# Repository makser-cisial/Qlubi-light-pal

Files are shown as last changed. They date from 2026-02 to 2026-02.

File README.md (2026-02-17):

# Qlubi-light-pal

A.M.D.G

A desktop buddy who’s there to connect when you feel most alone

Qlubi is a networked companion device that converts heart rate stress signals into anonymous light communication, enabling trusted groups to support each other remotely through subtle, non-verbal interaction.

<p float="left">
  
  
</p>

---

## What it is

Qlubi network-based device designed to connect groups working and living separately and provide accompaniment through its communicative light system. Composed of a microcontroller, button, LED strip, and limited 3D printed parts, the device allows user to create a network by which they can pick up on and engage with each other’s distress without surveillance or intrusion.

The project is open source and designed to be customised and built upon, turning each Qlubi into someone’s made to be buddy.

Watch the product video at: https://www.youtube.com/watch?v=_jfL0hginCQ
---

## Concept

Today’s world provides a uniquely extreme environment in the way that it has pushed social connection to its limit. No longer can one pick up on the body language of a colleague in the office to see they may be stressed and need a hand or a knowing glance. No one is there to notice when someone is stressed, so much so the person themselves doesn’t realise it either without the outside prodding of others. 

Qlubi exists to fill that space, bringing these non-verbal forms of communication and connection to the digital world. By syncing one’s heart rate data with the device, users can create trusted networks with friends where when one’s heart rate rises from stress, and an anonymous signal is sent throughout the network, allowing others to interact with their devices to send back heartening signals through warm waves of pulsating light.

---

## Key Questions

### Who’s connected?

Users can form intentional networks of devices with whoever they please, connecting through personal servers via MQTT protocol meaning you're only connected to those you know and trust.

### What travels through the network?

Only anonymised messages that shift the states of the devices as all heart rate data is processed locally keeping one’s data private and secure. You don’t know who’s stress you’re responding to or what may be stressing them out allowing outreach without exposure and support without interference.

### How come light?

Light allows for a soothing and non-jarring means of communication when compared to sound, allowing it to only just catch the users attention and alert them out of their stress cycle without activating any further stress response. Being light based also allows the device to function in public spaces without disturbing those near which also contributes to a more intimate and deliberate experience as you know someone out there is paying attention to your call.

### How does one interact with the device?

When receiving signals, users can pat their Qlubi’s head, pressing the internal button and thus responding and interacting with the network, turning what would have been cold keyboard clicks into an extension of warm physical touch. 

---

## How it works

- User’s heartrate data is streamed from their smart watch or device to their paired Qlubi system via a local HTTP connection  
- After establishing a baseline, a maintained spike in heartrate indicating stress may be detected  
- When this occurs, the system sends a signal via MQTT to all other active devices in the system who begin to gently pulsate indicating that there is a in-network user in distress  
- Those receiving this message can then tap their Qlubi on the head three times, sending a signal back to the original device telling it to begin pulsating a different colour indicating that they are stressed and someone has reached out  
- When there are no other active users or there is no response after a certain time the Qlubi acts autonomously, entering a slightly different alert mode simply to alert the user of their stress  

Through this others can pick up on what their friends and colleagues are feeling, allowing them to step into their space and be there through the Qlubi

---

## Design Intent

- Qlubi is currently developed as a prototype device intended for experimentation, iteration, and open maker development.
- The system is intended for both end users and makers interested in building connected devices, wearable interaction systems, and emotional communication tools.
- The device is built around:
  - Lolin S2 Mini microcontroller  
  - WLED compatible LED strip  
  - Lolin 1 Button  
  - A wearable capable of monitoring heart rate  
  - A sensor logger app on a mobile device synced with the wearable
- Everything included is open licence and intended to be shared, modified, and expanded upon by the community.

---

## Hardware

- The hardware platform is centred around the Lolin S2 Mini which provides wireless connectivity, local processing, and LED control capabilities.
- The lighting system uses compact WLEDs with 7 LEDs which provide device state feedback and interaction visualisation.
- The button is the Lolin 1 Button which provides touch interaction and allows users to physically respond to incoming network signals.
- Users must 3D print their own parts using the included enclosure and component mounting models provided in the repository.

---

## Software and System Behaviour

- The board firmware and laptop side software together manage the communication and interaction logic of the system.
- Firmware functionality includes:
  - Subscribing to wearable heart rate data streams
  - Establishing and maintaining a baseline heart rate
  - Detecting deviations from baseline values
  - Managing device operational states
- Network behaviour includes:
  - Communication using MQTT messaging
  - Broadcasting distress signals between devices
  - Handling pairing messages and confirmations
  - Managing response signals between users
- Laptop software functionality includes:
  - Acting as a bridge between wearable sensor logger data and MQTT broker topics
  - Publishing heart rate data to Qlubi devices
- Interaction logic includes:
  - Button tap sequences used for mode switching
  - Pairing initiation and confirmation
  - Triggering response signals
- LED behaviour communicates:
  - Device state
  - Incoming network signals
  - Pairing status
  - Response confirmation through pulsing patterns and colour changes

---

## Open Source from code to form

Hardware: open, reproducible and customisable through simple 3D printing  
Software: open source Circuit Python  
Concept: adaptable and extendable  (GitHub) 

Whilst having a specific aim, Qlubi’s framework allows for an extremely wide array of customisation as users print parts to make their Qlubi theirs and open code allows one to stack on as many features as they can think of.

---

## Build Requirements

- All that is needed is a 3D printer.
- No soldering or glueing required as all parts are friction fits and the enclosure is designed to hold every internal component securely.
- The only adhesive required is a strip of double sided tape used to hold the LED strip to the back wall of the enclosure.

---

## Assembly

There will be a separate document that contains full assembly instructions, build order, and placement diagrams. This repository references that document for the physical build process.

---

## Setup and Configuration

This section will contain:

- Firmware installation instructions  
- Network configuration guidance  
- MQTT broker setup instructions  
- Wearable sensor logger configuration  
- Device pairing instructions  
- Troubleshooting information  

This will be completed once the full GitHub repository structure is finalised.

---

## Customisation

- Qlubi can be printed in any colours and materials the user wants.
- Decorative and functional variations can be created using the provided 3D files.
- Expansion geometry allows attachments and custom add-ons to connect cleanly with the base device.
- All enclosure files and firmware are available for users to edit, modify, and extend to suit personal or project specific needs.

---

## Network Requirements

- One needs access to a server to set up a Qlubi network.
- The server acts as the MQTT broker which manages communication between wearable devices and all connected Qlubi units.

---

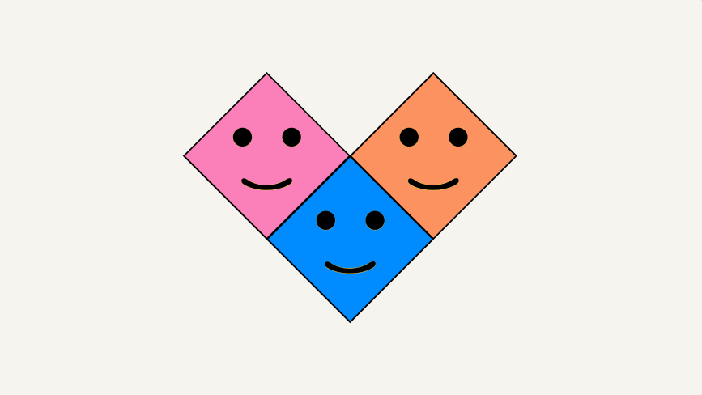
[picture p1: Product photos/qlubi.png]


## Why this matters

Qlubi incorporates this connected but anonymous form of network to both remove the shame of reaching out that drives disconnection whilst capitalizing on this alternate medium to take connection beyond where it could in the physical world. One can reach out through simply because there is someone that needs to be reached and can do so without feeling uncertain as to whether it is their place to. In a world that removes intimate connection, Qlubi highlights it and advances it

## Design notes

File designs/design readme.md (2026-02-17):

# Qlubi Face & Body Assembly Guide

Qlubi is composed of two primary printed structures: the **Face module** and the **Body enclosure**.

Each module has its own folder and printing instructions.  
You must complete the instructions within those folders before proceeding to final assembly described here.

This guide explains how both modules integrate into the complete Qlubi device.

---

## Overview of Composition

Qlubi consists of:

- Face Print  
- Body Enclosure (Base + Upper Shell)  
- Lolin S2 Mini  
- LEDs  
- Optional Hats  
- Boots  

No adhesive is required for standard assembly. All components are designed as friction-fit or mechanical lock-fit.

---

# Step 1 — Complete Folder Instructions

Before continuing:

1. Follow all printing instructions inside the **Face folder**.
2. Follow all printing instructions inside the **Body folder**.
3. Ensure all supports are removed cleanly.
4. Confirm scaling has not been altered in your slicer.

Only proceed once both printed assemblies are ready.

---

# Step 2 — Installing the Face into the Body

The Face is designed to slide vertically into the front cavity of the Body enclosure.

## Installation Process

1. Hold the Body upright.
2. Align the Face print with the internal guide rails.
3. Slide the Face downward slowly.
4. Continue sliding until it reaches the bottom.

At the base of the Body there is a **raised locking feature**.  
The Face contains a matching recess.

Push firmly until the Face locks into place against the raised internal stop.

The Face should:

- Sit flush  
- Not wobble  
- Not lift upward without deliberate force  

If resistance occurs:

- Check for leftover support material  
- Check for minor print stringing along rail edges  

Do not force excessively.

---

# Step 3 — Assembling the Lolin S2 Mini

Assemble your **Lolin S2 Mini** by 
1. soldering on the pin connectors
2. cutting off the excess from the button to ensure the board lies as flush as possible
3. place on the button in the correct orientation and then the LED wires accordingly going red, black green from the bottom right up

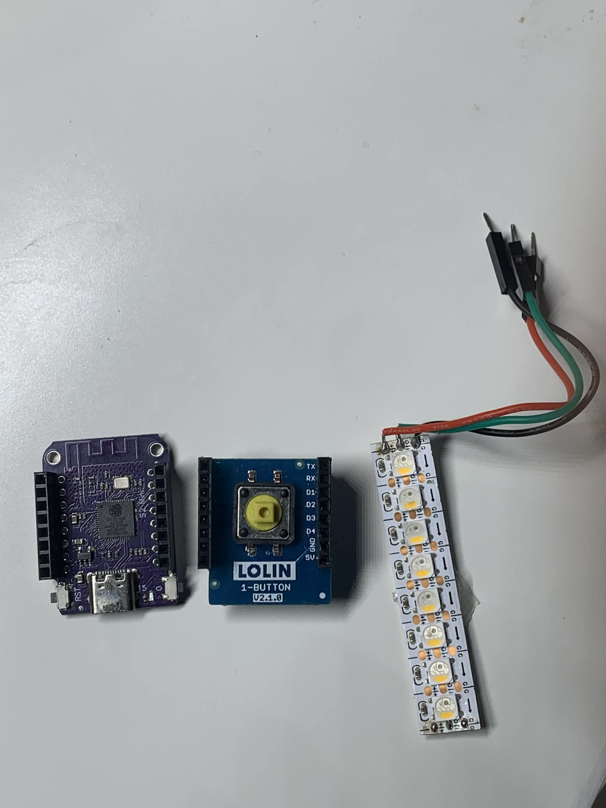
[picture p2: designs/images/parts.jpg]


Ensure:

- Pins are correctly soldered  
- LEDs are properly connected  
- No exposed contacts are shorting  

Test functionality before enclosure installation if possible.

---

# Step 4 — Installing the Board into the Base

1. Insert the Lolin S2 Mini into the base cavity.
2. Orient it so the **USB-C port faces the rear opening**.
3. Seat the board flat against the internal platform.

The USB-C port must remain accessible from the back of Qlubi for charging and programming.

Do not trap wires beneath the board.

---

# Step 5 — Installing the LEDs

1. Attach the LEDs to their designated mounting points.
2. Feed LED wiring through the bottom routing holes.
3. Route wires cleanly toward the base.

**Important:**

- Stick the LEDs to the **back interior wall** of the Body.  
- Ensure LEDs face forward toward the Face diffuser area.  
- Confirm no wires obstruct the LED light output.  
- Avoid crossing wires over the LED surface.  

Clean cable routing improves light diffusion and prevents shadowing.

---

# Step 6 — Closing the Body

Once:

- Face is locked in place  
- Board is seated  
- LEDs are positioned  
- Wiring is routed cleanly  

Place the **top shell** onto the Body.

Press down evenly until it seats fully.

---

# Step 7 — Accessories

## Hats

Insert any compatible hat into the top head slot.  
Hats are swappable and require no adhesive.

## Boots

Place boots into their corresponding lower body positions.  
They are designed as friction-fit components.

---

# Adhesives

No glue is required.

However, if your printer tolerances are loose, you may optionally use:

- Small pieces of double-sided tape  
- Minimal removable adhesive  

Avoid permanent glue unless modification is intentional.

---

# Final Check

Before powering on:

- Confirm USB-C port alignment  
- Confirm no wires are pinched  
- Confirm LEDs are unobstructed  
- Confirm Face is fully seated  

Qlubi should now be fully assembled and ready for operation.

---

# Troubleshooting

If components do not fit:

- Recheck scaling in slicer  
- Confirm correct STL files were used  
- Inspect for print warping  
- Remove residual supports fully  

---

Qlubi is modular by design.  
Face styles, hats, and colours can be interchanged without reprinting the full enclosure.

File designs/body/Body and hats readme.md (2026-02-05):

# Qlubi Body and Hats Printing Guide

The Qlubi body is fully 3D printed and designed to be easily produced using the files included in this repository. Users may either print the entire body in one print or print individual parts separately to customise colours, materials, or finishes.

---

## Available Files

The repository contains multiple options depending on how you would like to print your Qlubi body.

### Qlubi Full

- `Qlubi full.stl`  
  Contains all body and hat components combined into a single print file. 

---

### Qlubi Body Zip

- `Qlubi body.zip`  
  Contains all Qlubi body components as separate files.  
  This allows users to print body sections individually or in different colours and materials.

---

### Hats Zip

- `Hats.zip`  
  Contains all hat components as separate files.  
  Hats can be printed individually and swapped depending on user preference.

---

## Printing Options

Users have two primary approaches when printing Qlubi.

---

## Option 1 — Print Entire Body at Once

1. Import `Qlubi full.stl` into your slicer.
2. Split the model into objects and orient as relevant as can be seen in image.
3. Enable supports as required.

### Recommended Print Settings

- Infill: **5–15%**
  - Use higher infill for lighter or more translucent materials to reduce light leakage.
  - Use lower infill for darker or more opaque materials.

- Layer Height: **0.16 mm**

- Supports: **Snug supports recommended**

This method is the fastest and simplest way to produce a complete Qlubi enclosure.

---

## Option 2 — Print Parts Separately

Users may unzip the body and hat archives to print components individually.

### Benefits of Printing Parts Separately

- Allows multi-colour printing
- Allows mixing materials
- Enables easier reprinting of damaged or modified parts
- Supports aesthetic customisation and personal styling

### Process

1. Extract `Qlubi body.zip`.
2. Extract `Hats.zip`.
3. Import individual STL files into your slicer.
4. Arrange and print parts according to your chosen colour or material layout.

Recommended print settings remain the same as printing the full body unless specific materials require adjustment.

---

## Material Considerations

- Lighter or translucent filaments may allow more internal light leakage and benefit from higher infill percentages.
- Darker or opaque filaments naturally reduce light leakage.

---

## Assembly

Line up all printed parts and press them together as designed.

Ensure that the springs are correctly placed in position between the base and the upper casing before fully closing the body. Proper spring placement is required for correct button interaction and device function.

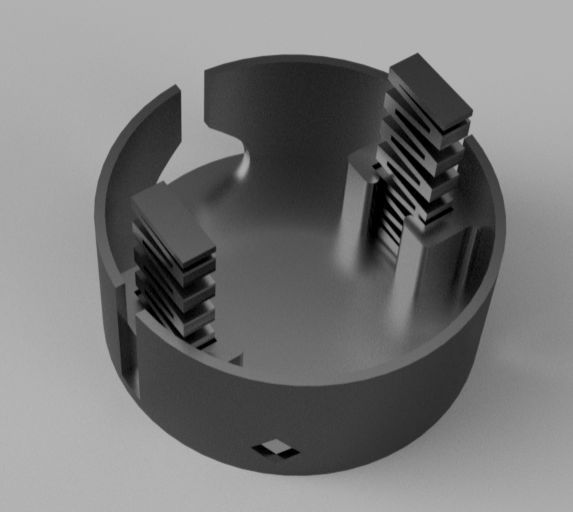
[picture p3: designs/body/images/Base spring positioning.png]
Spring positioning for base


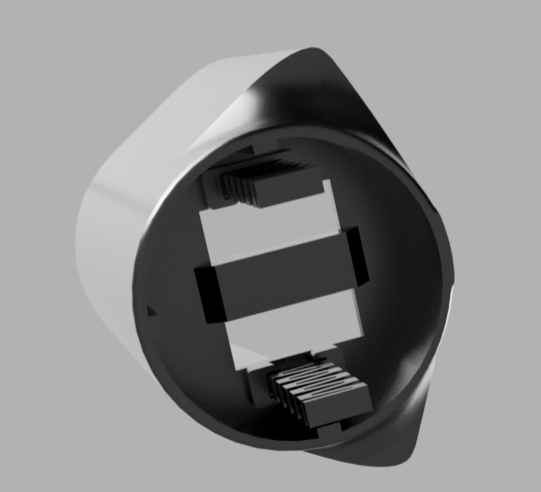
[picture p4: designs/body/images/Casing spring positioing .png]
Spring positioning for casing


---

## Troubleshooting

If parts do not fit correctly:

- Confirm scaling has not been altered in the slicer
- Confirm supports were removed cleanly
- Confirm correct parts were printed for the intended assembly

---

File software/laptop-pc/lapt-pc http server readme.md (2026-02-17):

# Laptop/PC HTTP Code Setup Guide

This folder contains the Laptop/PC HTTP code required to connect your Qlubi device to your HTTP server infrastructure to connect your app to your MQTT server broker and protecting your data..

To run this code, users must first configure a local Python environment on their computer.

This guide outlines the full setup process.

---

# Step 1 — Install a Python interpreter

You will need a Python IDE or runtime environment to execute the code in this folder.

You may use any Python interpreter of your choice.

One recommended option is **PyCharm**, which is stable and beginner-friendly.

Download PyCharm here:  
https://www.jetbrains.com/pycharm/

Install the Community Edition unless you require advanced features.

---

# Step 2 — Prepare the Project

Once PyCharm (or your chosen runner) is installed:

1. Open the application.
2. Create a new Python project.
3. Open the main Python file provided in this folder.
4. Copy the contents of the code.
5. Paste the code into your new project file.

Ensure the file is saved with a `.py` extension.

---

# Step 3 — Configure the Code for Your Setup

Before running the script, you must modify the configuration variables to match your system.

Specifically update:

- Device ID
- Board details
- Server address (IP or domain)
- Port configuration (if applicable)
- Any authentication keys or tokens

Refer to the below reference image in this repository to see where these fields are located in the code.

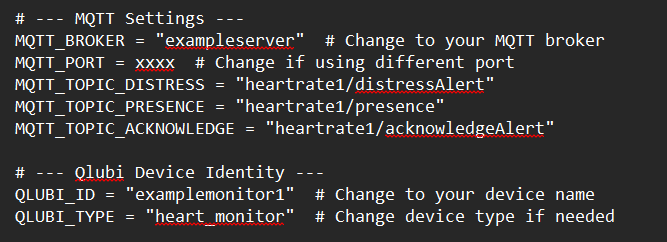
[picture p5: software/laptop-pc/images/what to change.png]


Failure to update these values will prevent proper communication between:

- Laptop client
- Server
- Board (Lolin S2 Mini)
- Application interface

---

# Step 4 — Run the Script

After configuration:

1. Click **Run** in your Python environment.
2. The IDE may prompt you to install missing libraries.

Accept all required library installations.

Typical libraries may include:

- `requests`
- `flask`
- `json`
- `time`
- `threading`
- or other networking dependencies

Allow the environment to complete installation.

---

# Step 5 — Re-run the Script

Once all dependencies are installed:

1. Run the script again.
2. Confirm that no import errors occur.
3. Observe the console output for successful server communication messages.

If correctly configured, the HTTP client should now be operational.

---

# Final System Check

Before active use, ensure:

- Server is running
- Board is powered and connected to WiFi
- App interface is active
- Correct IP addresses are configured
- Firewall settings are not blocking communication

All three components — **server, app, and board** — must be operational for full functionality.

---

# Troubleshooting

If the script does not run:

- Confirm Python is installed on your system
- Confirm the correct interpreter is selected in your IDE
- Confirm libraries installed successfully
- Verify server address is reachable
- Check that port numbers match your server configuration

---

Once complete, your Laptop7PC HTTP bridge should be fully operational and ready for integration with Qlubi.

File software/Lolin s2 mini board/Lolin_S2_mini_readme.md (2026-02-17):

# Qlubi Board Code Setup Guide (Lolin S2 Mini)

This folder contains the CircuitPython board code required to run Qlubi on the Lolin S2 Mini.

Before uploading this code, users must first prepare their board with CircuitPython and configure it to match their WiFi network and server.

This guide outlines the full setup process from firmware installation to final deployment.

---

# Step 1 — Install CircuitPython on the Lolin S2 Mini

The Lolin S2 Mini must be running CircuitPython before the board code will function.

Follow the official installation guide here:

https://circuitpython.org/board/lolin_s2_mini/

Follow the flashing instructions provided on that page to install the correct UF2 firmware.

After successful installation:

- The board should mount as a USB drive named `CIRCUITPY`
- Default files such as `code.py` should be visible

Do not proceed until CircuitPython is properly installed and the board mounts correctly.

---

# Step 2 — Download and Configure the Board Code

Download the board code from this folder.

Before transferring it to the board, you must edit the configuration values to match your setup.

Update:

- WiFi SSID
- WiFi password
- Server IP address or domain
- Server port (if required)
- Device/board identifier
- HTTP endpoint configuration

If these values are not set correctly, the board will not connect to your network or server and will not function.

Ensure each board has a unique identifier if running multiple devices.

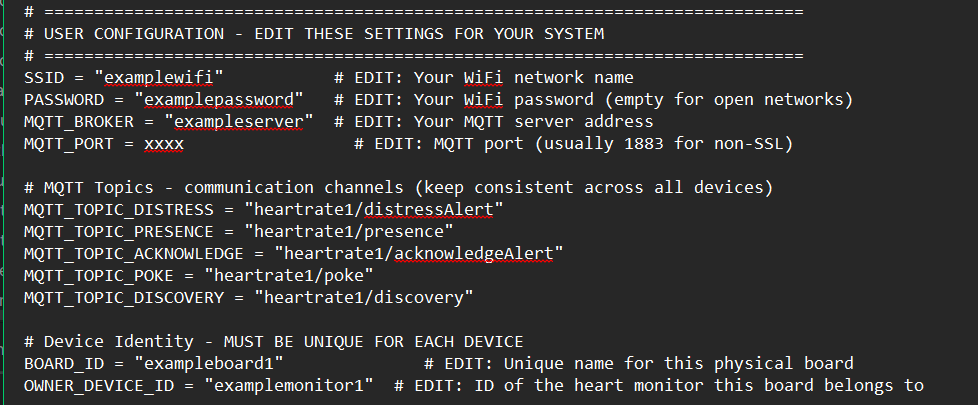
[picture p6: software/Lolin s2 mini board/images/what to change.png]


---

# Step 3 — Upload the Code to the Board

You have two supported upload methods.

---

## Option 1 — Manual File Copy

1. Connect the Lolin S2 Mini to your computer.
2. Open the `CIRCUITPY` drive.
3. Replace the existing `code.py` file with the configured version from this folder.
4. Copy any additional required files into the root directory.

Ensure the main script file is named:

code.py

CircuitPython automatically runs `code.py` on boot.

---

## Option 2 — Recommended: Use Mu Editor

For easier debugging and serial monitoring, Mu Editor is recommended.

Download Mu here:

https://codewith.mu/

### Using Mu:

1. Open Mu.
2. Select CircuitPython mode.
3. Connect your board.
4. Paste the board code into the editor.
5. Press **Save** and save directly to the board as `code.py`.

Mu allows you to:

- Establish a live serial connection
- View runtime output
- Debug connection issues
- Monitor errors in real time

This is the recommended method for development and troubleshooting.

---

# Step 4 — Replace the `lib` Folder

The board requires specific CircuitPython libraries.

You must:

1. Delete any existing `lib` folder on the `CIRCUITPY` drive.
2. Copy the `lib` folder provided in this repository onto the board.

Your board file structure should look like:

CIRCUITPY/
│
├── code.py
├── lib/
│ ├── (required CircuitPython libraries)

If required libraries are missing, the board will display `ImportError` messages on startup.

---

# Step 5 — Power and Test

Once:

- CircuitPython is installed
- `code.py` is uploaded
- WiFi and server values are configured
- `lib` folder is correctly replaced

Reset the board.

If configured correctly:

- The board should connect to WiFi
- It should establish HTTP communication with your server
- Serial output (via Mu) should confirm successful connection

---

# Final System Check

Before full operation, confirm:

- Server is running
- HTTP endpoint is active
- Laptop7PC HTTP bridge (if used) is running
- WiFi credentials are correct
- Firewall is not blocking outbound requests

The board depends on a reachable server to function correctly.

---

# Troubleshooting

If the board does not operate as expected:

- Recheck WiFi credentials
- Confirm server IP address and port
- Verify correct HTTP endpoint path
- Ensure the `lib` folder contains required libraries
- Monitor serial output in Mu for error messages
- Confirm CircuitPython version matches library compatibility

---

Once all steps are complete, your Lolin S2 Mini should be fully configured and ready to operate within the Qlubi system.

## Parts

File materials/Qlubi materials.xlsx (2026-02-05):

Qlubi Bill of materials
 | Details | Pieces lot | Price lot | Price Piece | Parts | Price parts | Link
PLA filament | 1.75mm dark coloured filament for body and all hats | 1 | 12.99 | 12.99 | 1 | 1.62 | https://eu.elegoo.com/products/pla-filament-1-75mm-colored-1kg
PLA filament | 1.75mm light coloured for face | 1 | 12.99 | 12.99 | 1 | 0.09 | https://eu.elegoo.com/products/pla-filament-1-75mm-colored-1kg
WLED strip 7 LED | 1144 LED/m sk6812 | 144 | 9.8 | 0.068 | 7 | 0.48 | http://it.aliexpress.com/item/1m-4m-5m-WS2812B-Smart-led-pixel-strip-Black-White-PCB-30-60-144-leds-m/2036819167.html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
Lolin S2 mini |  | 1 | 5.9 | 5.9 | 1 | 5.9 | https://it.aliexpress.com/item/1005003145192016.html?gatewayAdapt=glo2ita
1-Button Shield V2.1.0 for LOLIN Mini Button (WEMOS) D1 |  | 1 | 1.67 | 1.67 | 1 | 1.67 | https://it.aliexpress.com/item/32575988167.html
Pin connectors |  | 20 | 1.73 | 0.086 | 4 | 0.35 | https://it.aliexpress.com/item/1005005488898046.html?curPageLogUid=9nn9l35GNDs7 (http://it.aliexpress.com/item/Free-Shipping-400pcs-dupont-cable-jumper-wire-dupont-line-female-to-female-dupont-line-20cm-1P/1727878715.html)
connecting wires |  | 40 | 0.64 | 0.016 | 3 | 0.05 | http://it.aliexpress.com/item/40pcs-lot-10cm-2-54mm-1pin-feMale-to-feMale-jumper-wire-Dupont-cable/32226515120.html
USBC Cable |  | 1 | 1.83 | 1.83 | 1 | 1.83 | https://it.aliexpress.com/item/1005010315165505.html?curPageLogUid=8XlTOzHhoJHw (http://it.aliexpress.com/item/Fedex-shipping-100pcs-lot-3M-Noodle-flat-color-USB-Micro-cable-for-HTC-Samsung-Galaxy-S3/1472726264.html)
 |  |  |  |  | TOTAL € | 11.99

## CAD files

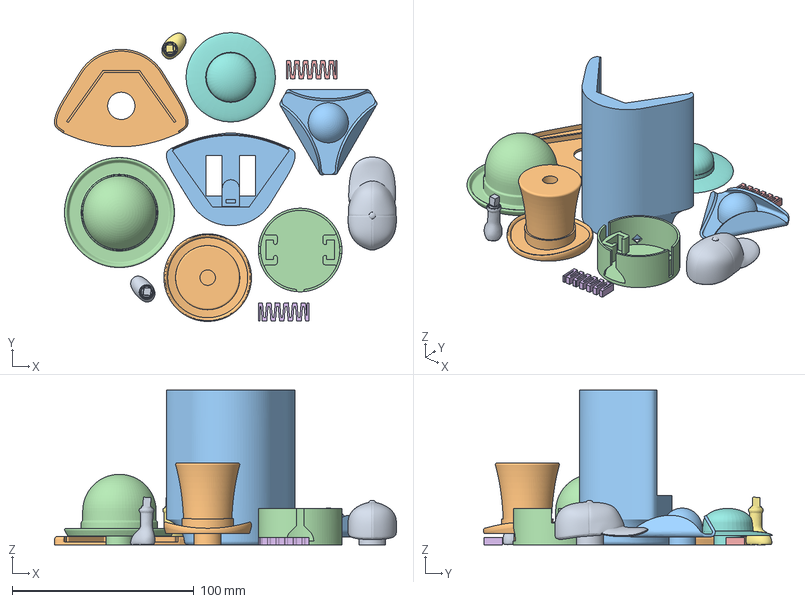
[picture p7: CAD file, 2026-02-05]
designs/body/Qlubi body layout for slicer.3mf
188.1 x 158.9 x 85.0 mm
Qlubi full.stl_1
Qlubi full.stl_2
Qlubi full.stl_3
Qlubi full.stl_4
Qlubi full.stl_5
Qlubi full.stl_6
Qlubi full.stl_7
Qlubi full.stl_8
Qlubi full.stl_9
Qlubi full.stl_10
Qlubi full.stl_11
Qlubi full.stl_13

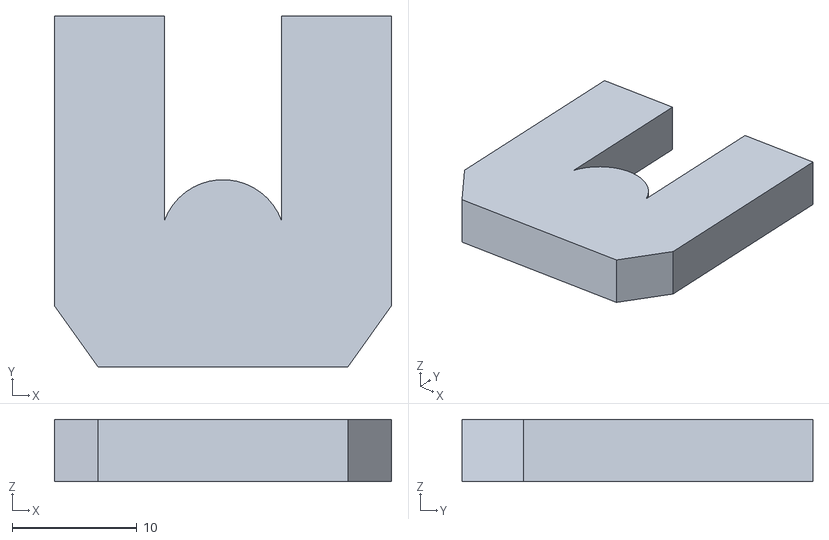
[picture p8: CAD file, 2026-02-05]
designs/face/inverse face cut.stl
27.0 x 28.1 x 5.00

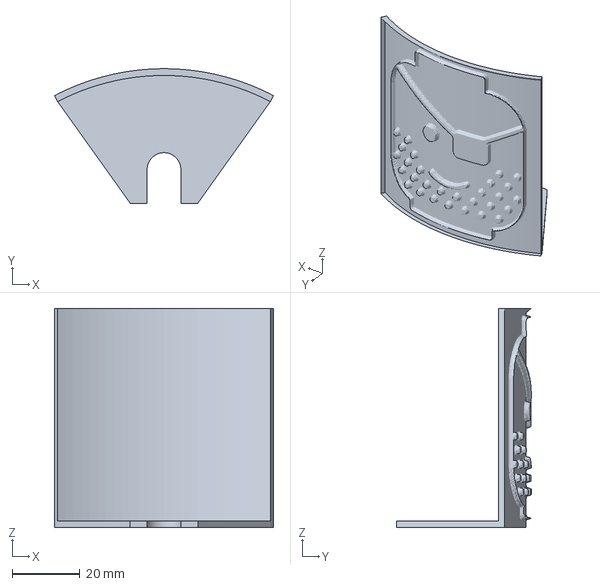
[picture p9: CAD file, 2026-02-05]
designs/face/Face layout for slicer.3mf
64.9 x 39.9 x 65.0 mm

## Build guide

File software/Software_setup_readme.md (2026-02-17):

# Qlubi — Full System Setup & Operation Guide

This guide explains the complete process required to get Qlubi fully operational.

Qlubi relies on four coordinated components:

- MQTT Broker  
- HTTP Server  
- Sensor Logger App (Heart Rate Source)  
- Lolin S2 Mini Board (Qlubi Device)  

All components must be configured correctly for full functionality.

---

# Step 1 — Establish an MQTT Broker

Qlubi requires an active MQTT broker to manage communication between devices.

If you already operate an MQTT broker, you may use that.

If not, this resource provides detailed comparisons of free MQTT broker options:

https://sourceforge.net/software/mqtt-brokers/free-version/#

Choose a broker that supports:

- Public or hosted deployment  
- Custom topic configuration  
- Username/password authentication (recommended)  
- Stable uptime  

---

## Configure Your Broker

Once your broker is established:

1. Create your broker instance.
2. Define:
   - Broker URL (domain or IP)
   - Broker port
   - Username (if required)
   - Password (if required)
3. Save these details.

You will paste these values into:

- Board code  
- Laptop HTTP bridge code  
- Server configuration  

Without matching credentials across all systems, communication will fail.

---

# Step 2 — Install and Configure Sensor Logger

Qlubi uses **Sensor Logger** as the heart rate data source.

Official website:  
https://www.tszheichoi.com/sensorlogger

Download Sensor Logger from your device’s app store and install it.

Sensor Logger must be connected to your smartwatch or heart rate monitor.

---

## Sensor Logger Configuration

After installation:

1. Connect your smartwatch or heart rate monitor.
2. Enable **heart rate monitoring only** (disable unnecessary sensors).
3. Open **Settings** in Sensor Logger.
4. Enable **Data Streaming (HTTP Push)**.
5. Enter:
   - Your HTTP server URL
   - Your HTTP server port

⚠ Important:

- The HTTP server IP and port may change depending on your network.
- Always verify these values before starting a session.
- Your phone/device and HTTP server must be on the same internet connection.

If they are not on the same network, data will not reach your server.

---

# Step 3 — Prepare the HTTP Server

Your HTTP server must be:

- Running  
- Listening on the configured port  
- Accessible from your phone/device  
- Configured to relay or process data as required  

If your HTTP server is not running:

- Qlubi devices may still communicate via MQTT.
- However, no heart rate data will be processed.
- No stress detection will trigger alerts.

For full functionality, the HTTP server must be active.

---

# Step 4 — Prepare the Qlubi Board

Ensure:

- CircuitPython is installed.
- Board code includes:
  - WiFi credentials  
  - Broker URL  
  - Broker port  
  - Device identifier  
- The board connects successfully to WiFi.
- The board connects successfully to MQTT.

Power on the Qlubi device before beginning use.

---

# Step 5 — Starting a Session

To fully activate Qlubi:

1. Power on your Qlubi device.
2. Start your HTTP server.
3. Open Sensor Logger.
4. Begin a heart rate recording session.

Once recording begins:

- Heart rate data is pushed to your HTTP server.
- The server processes incoming data.
- If distress thresholds are reached:
  - MQTT messages are triggered.
  - Connected Qlubi devices activate.

---

# Important Operational Notes

- Qlubi devices can communicate via MQTT even if the HTTP server is not running.
- Without the HTTP server:
  - No heart rate tracking occurs.
  - No stress detection occurs.
  - No distress alerts will be triggered.

To enable full functionality:

- Sensor Logger must be actively recording.
- HTTP server must be running.
- MQTT broker must be online.
- Board must be powered and connected.

---

# Daily Use Workflow

When sitting down to work:

1. Power on Qlubi.
2. Verify WiFi connection.
3. Confirm HTTP server is running.
4. Start heart rate recording in Sensor Logger.
5. Confirm data is being received by the server.

Qlubi will now monitor stress levels and activate alerts when thresholds are exceeded.

The more Qlubis in one's network the better the device experience so feel free to set them up for friends and family

---

# Troubleshooting Checklist

If alerts are not triggering:

- Confirm MQTT broker is online.
- Confirm broker credentials match across all systems.
- Confirm HTTP server is running.
- Confirm correct IP and port are set in Sensor Logger.
- Confirm Sensor Logger is actively recording.
- Confirm all devices are on the same network.
- Check firewall settings.
- Verify board serial output for connection errors.

---

Once all systems are synchronized, Qlubi will operate as a live stress-aware communication device.

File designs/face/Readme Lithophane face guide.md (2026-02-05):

# Qlubi Face Lithophane Guide

The face of Qlubi is created using a 3D printed lithophane panel. This panel displays an image chosen by the user and is illuminated from behind by Qlubi’s internal lighting system.

This guide explains how to generate the lithophane file and prepare it for printing and assembly. One can also use the premade STL models in this folder and skip to step 4.

---

## Creating the Lithophane

Qlubi uses a lithophane generated using the following tool:

👉 https://www.lithophanemaker.com/Night%20Light%20Lithophane.html

---

## Step 1 — Enter the Required Settings

Enter the following settings exactly as listed below before uploading your image. This ensures you understand the size and shape limitations your image must fit within.

- Lithophane resolution: **0.25 mm/pixel**
- Maximum thickness: **2 mm**
- Minimum thickness: **0.5 mm**
- Frame width: **0 mm**
- Slot width: **10 mm**
- Slot depth: **10 mm**
- Adapter thickness: **2 mm**
- Light-to-lithophane distance: **30 mm**
- Radius of curvature / flatness: **67.5 mm**
- Night light width: **64 mm**
- Night light height: **64 mm**
- 
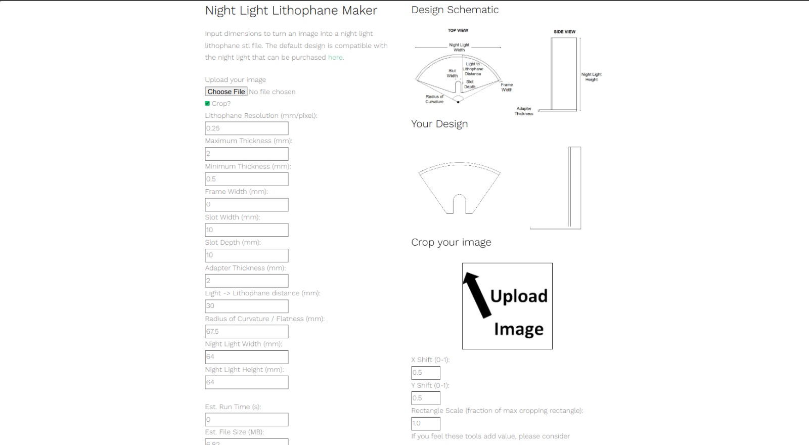
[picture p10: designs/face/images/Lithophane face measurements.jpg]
Lithophane measurements and site


---

## Step 2 — Upload and Adjust Your Image

1. Upload an image of your choice.
2. Adjust your image cropping and scaling so that the important parts of the image fit well within the defined square lithophane area.

Users may use any image they like whoever simple, black and white images on a plain background are ideal for a clear uncluttered face. It is also ideal to centre one's image an not have details too close to the edges to ensure they are not obscured by the lip of the casing.

---

## Important Notes

- Do **not change any settings** listed above.
- The only setting that may be adjusted is **Lithophane resolution** if:
  - Your printer is capable of higher detail printing.
  - You want a higher resolution image result.

Changing other settings will cause the lithophane to not fit the Qlubi enclosure correctly.

---

## Step 3 — Download the Lithophane

Once all settings are entered and your image is positioned correctly:

1. Generate the lithophane.
2. Download the generated STL file.

---

## Step 4 — Preparing the Lithophane for Qlubi

Qlubi requires the lithophane to be combined with an inverse face cut file before printing.

### Process

1. Import your downloaded lithophane STL into your slicer.
2. Import the **Inverse Face Cut** file provided in this repository.
3. Set the Inverse Face Cut file as a **negative volume**.
4. Position the negative volume according to the **Face Layout for Slicer** reference file.
5. Slice and export the final print file.

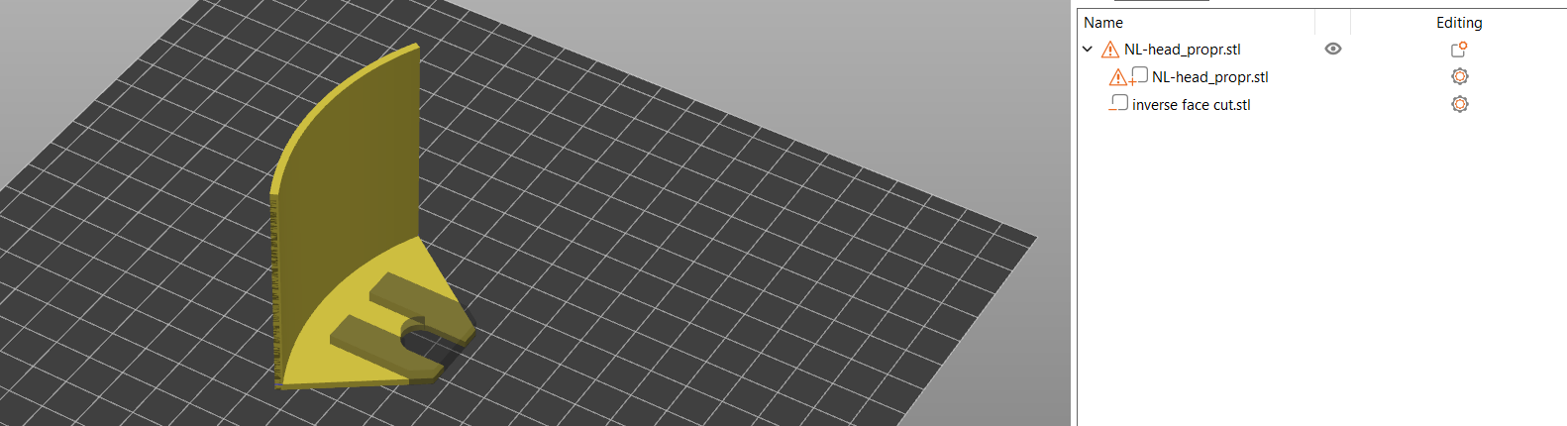
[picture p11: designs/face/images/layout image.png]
Layout image for comparison


---

## Printing Recommendations

- Print using a light-coloured or white filament for best light diffusion.
- Use a fine layer height such as 0.10mm for best image quality.
- Infill settings only impact base so anywhere from 5% to 15% is ideal
- Ensure consistent extrusion for smooth gradient transitions.

---

## Result

Once printed and installed, the lithophane becomes the illuminated face of Qlubi, allowing each device to have a unique and personal visual identity.

---

## Troubleshooting

If the lithophane does not fit:

- Confirm all dimensions were entered correctly.
- Confirm the inverse face cut file was used.
- Confirm the lithophane was not rescaled in the slicer.

---

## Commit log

2026-02-04 Create STL files
2026-02-05 Create List of materials
2026-02-05 STL body and hats
2026-02-05 Add files via upload
    STL files for the body, feet, and hats
